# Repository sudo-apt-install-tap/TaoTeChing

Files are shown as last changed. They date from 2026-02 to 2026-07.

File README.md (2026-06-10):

# Tao Te Ching

Split keyboard. Ortholinear grid with column stagger. Built for comfort and long sessions.

---

## Overview
Tao Te Ching is a **split mechanical keyboard** that combines the predictability of ortholinear rows with the ergonomics of column stagger. Each half is compact, symmetric, and designed to keep hands in a neutral position.

### Why?
This will be my first split keyboard. Ive seen many people make splits. But nearly noone uses custom layout. So I made this layout.

### How?
You can write up a simple firmware or use the KMK script in my repo.

---

## Layout
- Split, mirrored halves  
- Ortholinear rows with column stagger  
- Compact layout with outer thumb/utility keys  
- Optimized for touch typing and minimal finger travel

See renders and PCB files for exact spacing and geometry.

---

## Index:
- [Build Guide](https://github.com/sudo-apt-install-tap/TaoTeChing/blob/main/Build%20guide.md)
- [Build Images](https://github.com/sudo-apt-install-tap/TaoTeChing/blob/main/README.md#build-images)
- [Journal](tao-te-ching-journal.md)
- [Images](Images)
- [PCB](PCB)
- [Fimware](firmware)
- [CAD](CAD)
  
---

## Hardware
- MX-compatible switches  
- Per-key diodes (matrix)  
- Controller footprint suitable for XIAO-class boards  
- Board-to-board connection pads for split communication

Plates can be 3D-printed (PLA works) or CNCed.

---

## Firmware
Designed to work with common keyboard firmware:
- QMK / KMK / ZMK (controller-dependent)
I will use KMK

---

## Renders
- KiCAD Render: <br>
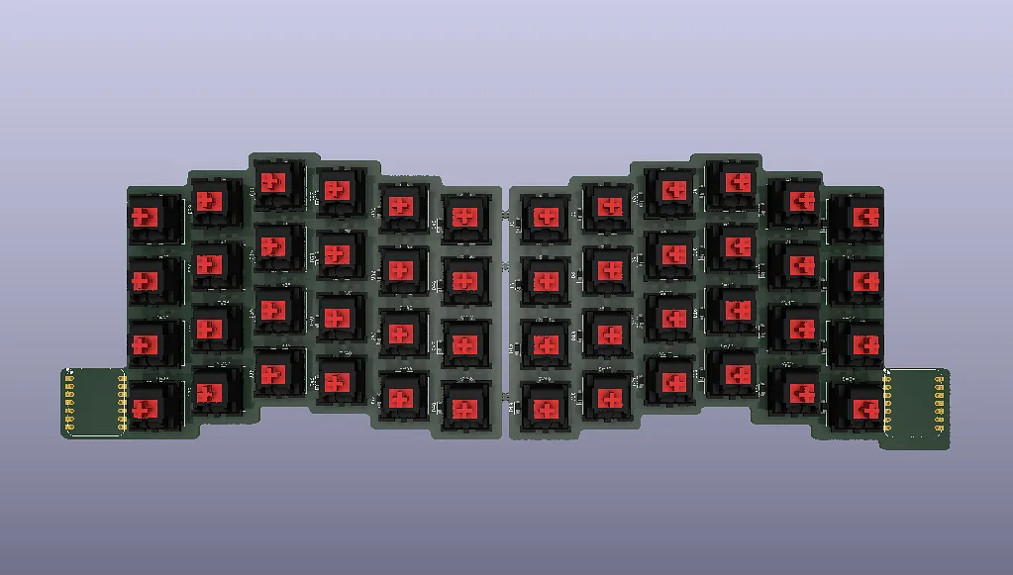
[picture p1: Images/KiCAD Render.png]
  
- CAD Exploded: <br>
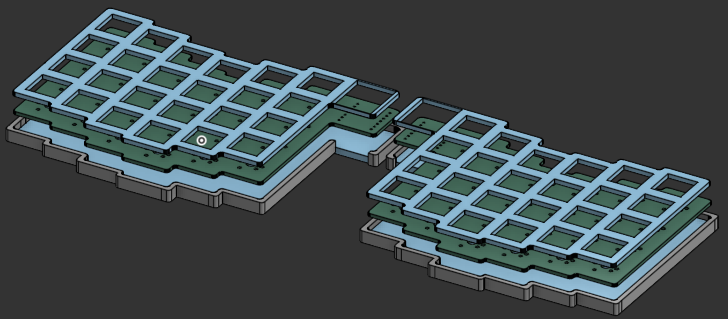
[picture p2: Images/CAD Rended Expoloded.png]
  
- CAD Assembled: <br>
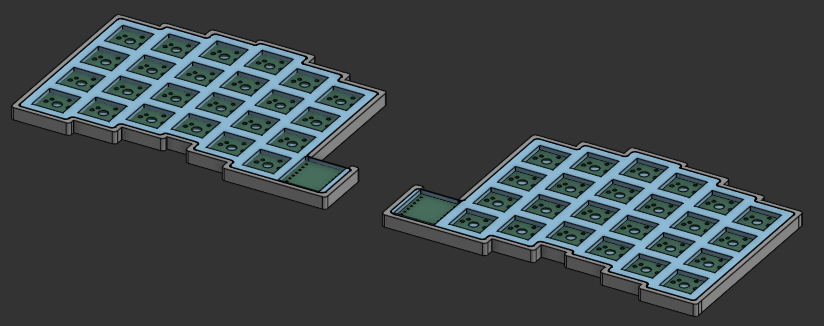
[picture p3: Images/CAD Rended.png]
  
- Left Case: <br>
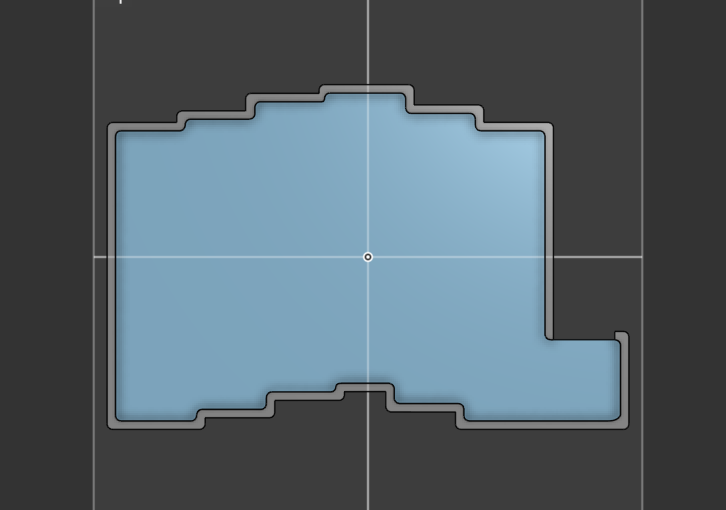
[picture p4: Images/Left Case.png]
  
- Right Case: <br>
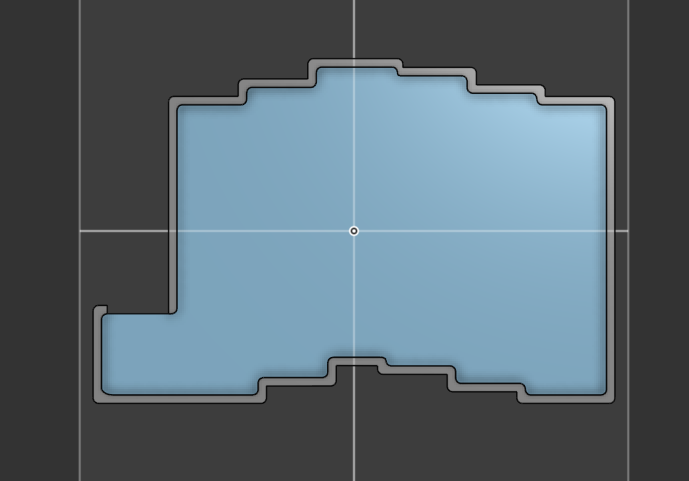
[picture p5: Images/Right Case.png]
  
- Left Plate: <br>
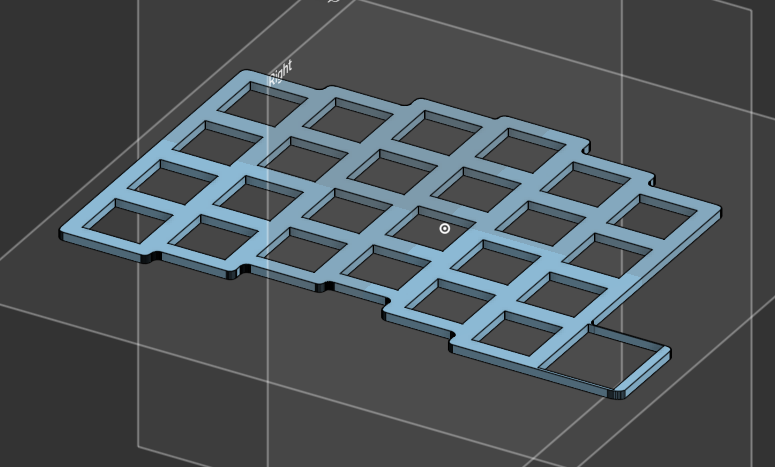
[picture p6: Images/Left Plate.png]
  
- Right Plate: <br>
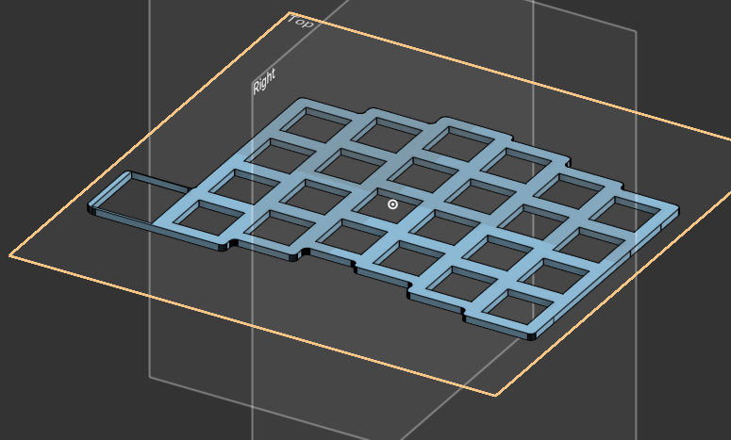
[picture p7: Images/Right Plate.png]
  
  
---

## KiCAD Images
- Layout: <br>
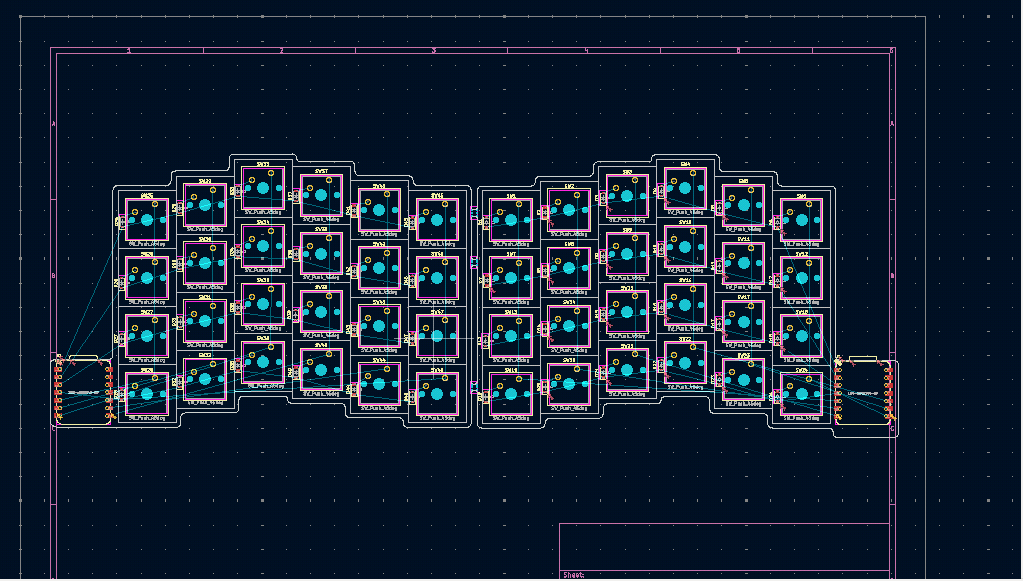
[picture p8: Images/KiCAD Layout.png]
  
- Left Sheet: <br>
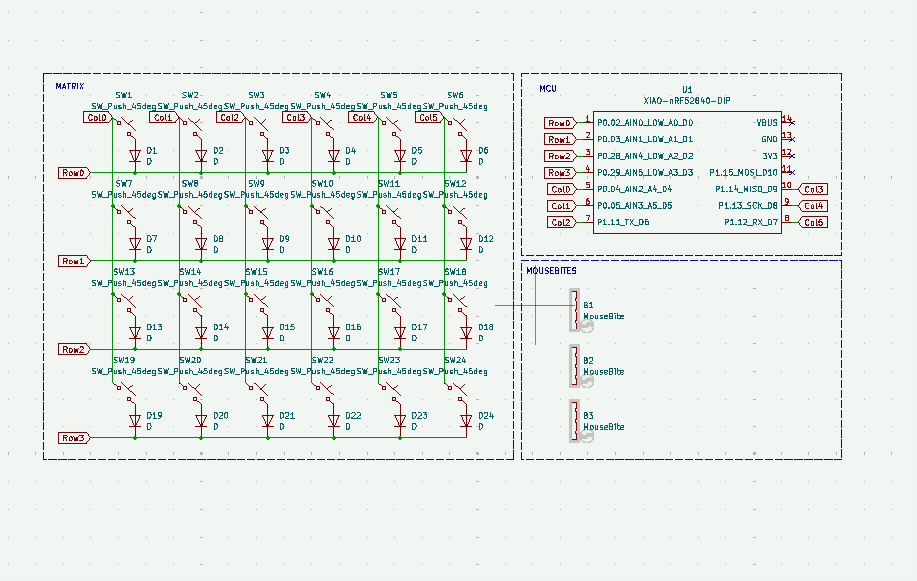
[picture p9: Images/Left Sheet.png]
  
- Right Sheet: <br>
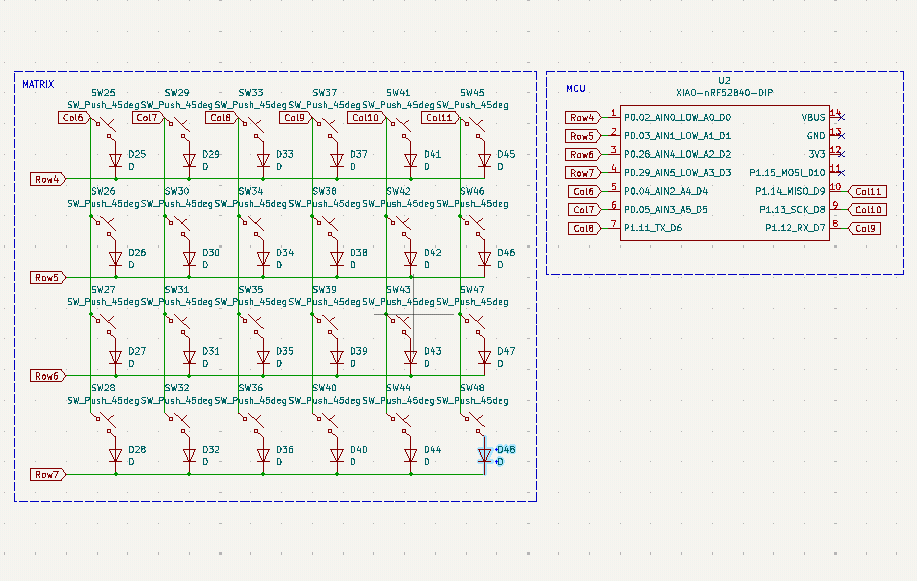
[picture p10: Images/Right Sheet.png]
  
- Wiring: <br>
  
  
---

## Project Status
- [x] Layout: finalized  
- [x] PCB: routed and rendered  
- [x] Prototypes: Done!
- [x] Revisions: Done!

### DONE!!

---

## Build Images And Videos
<div align="center">

 <br><br>
 <br><br>
 <br><br>
<br><br>
<br><br>
<br><br>
<br><br>

[TAO TE CHING DEMO](https://www.youtube.com/shorts/A5UJ3Mnc8bE)

</div>

---

# Bill of Materials (BOM)

| Item | Description | Cost (INR) |
|---|---|---:|
| Keycaps | Full keycap set | ₹1,400 |
| PCB | Custom PCB fabrication | ₹3,726 |
| Switches | Mechanical keyboard switches | ₹1,275 |
| Diodes | Per-key matrix diodes | ₹102 |
| MCU | Seeed Studio XIAO RP2040 | ₹1,236 |
| Case & Plate | 3D printed case and plate (shipping included) | ₹500 |
| **Total** |  | **₹8,239** |

> **Project Cost:** ₹8,239 (~$95 USD)

## CAD SOURCE FILES AVAILABLE!

[ONSHAPE](https://cad.onshape.com/documents/3a64b1ece82f2d5ea6875226/w/4aeac85fe30a56c6319ae754/e/e0c4af6436b0f9ae25f54182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)

---

## License
Open source. Build it, modify it, improve it.

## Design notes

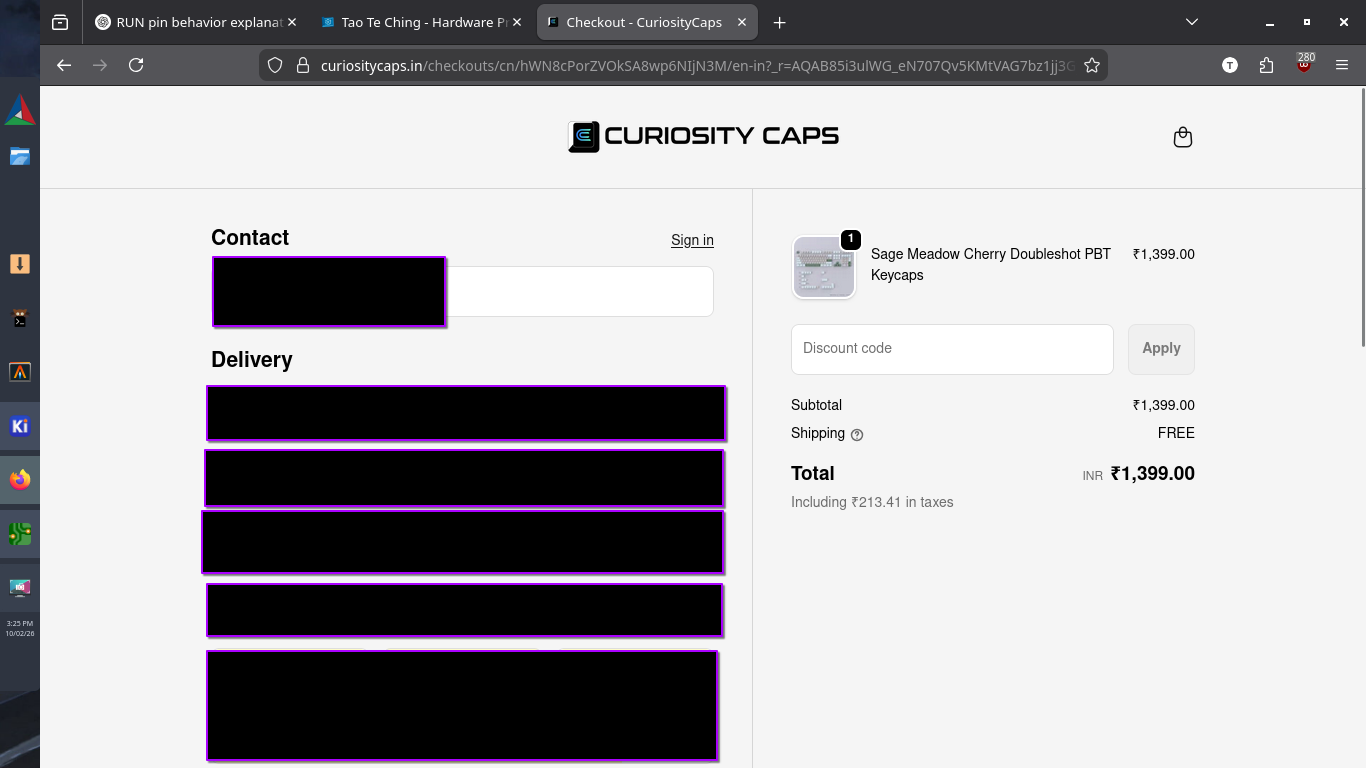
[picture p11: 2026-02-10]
Images/CART/Keycaps.png

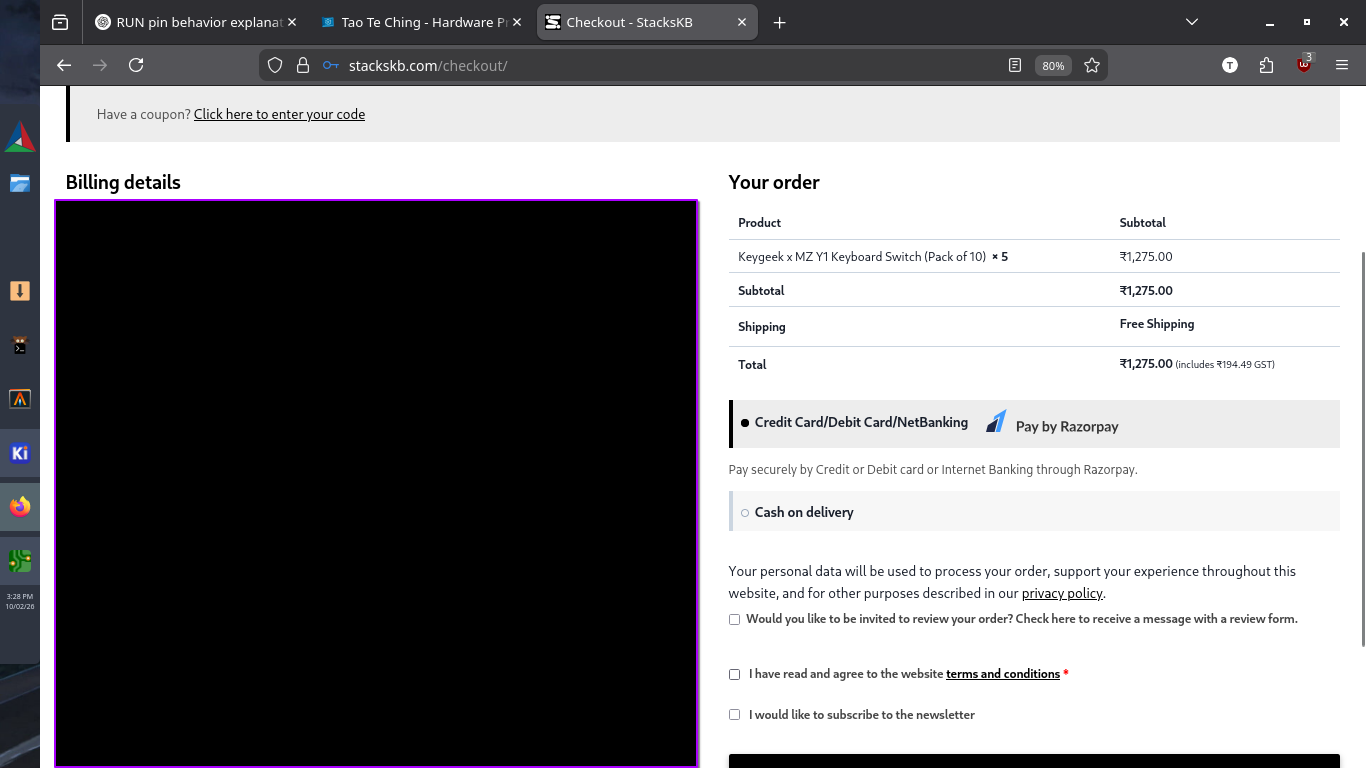
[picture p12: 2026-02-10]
Images/CART/StackKB Switches.png

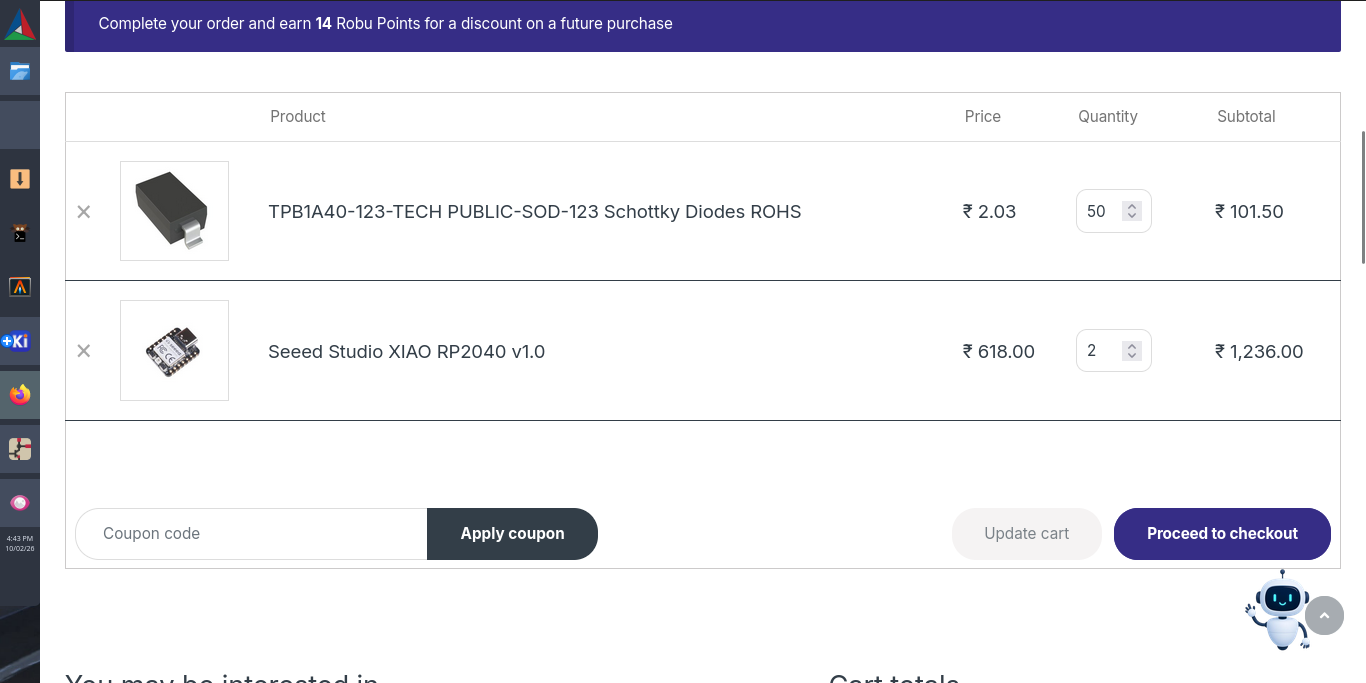
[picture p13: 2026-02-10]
Images/CART/Robu MCU + Diodes.png

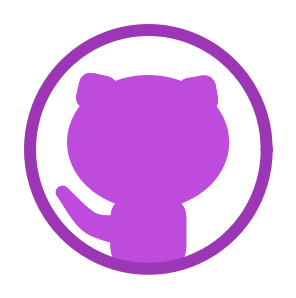
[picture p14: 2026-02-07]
Images/Git.png

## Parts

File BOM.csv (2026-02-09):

Id | Designator | Footprint | Quantity | Designation | Supplier and ref
1 | D22,D38,D41,D42,D44,D19,D25,D39,D40,D23,D16,D18,D35,D24,D17,D14,D48,D32,D27,D5,D13,D29,D28,D7,D6,D8,D1,D45,D21,D46,D43,D33,D15,D10,D34,D4,D30,D3,D37,D2,D36,D20,D26,D12,D11,D47,D31,D9 | D_SOD-123 | 48 | D
2 | SW17,SW30,SW38,SW12,SW33,SW23,SW46,SW28,SW45,SW13,SW24,SW44,SW35,SW2,SW42,SW20,SW22,SW43,SW11,SW4,SW47,SW36,SW9,SW41,SW26,SW39,SW48,SW18,SW6,SW7,SW15,SW1,SW5,SW27,SW8,SW31,SW21,SW40,SW16,SW37,SW14,SW29,SW10,SW32,SW3,SW34,SW25,SW19 | SW_Cherry_MX_1.00u_PCB | 48 | SW_Push_45deg
3 | U1,U2 | XIAO-nRF52840-DIP | 2 | XIAO-nRF52840-DIP

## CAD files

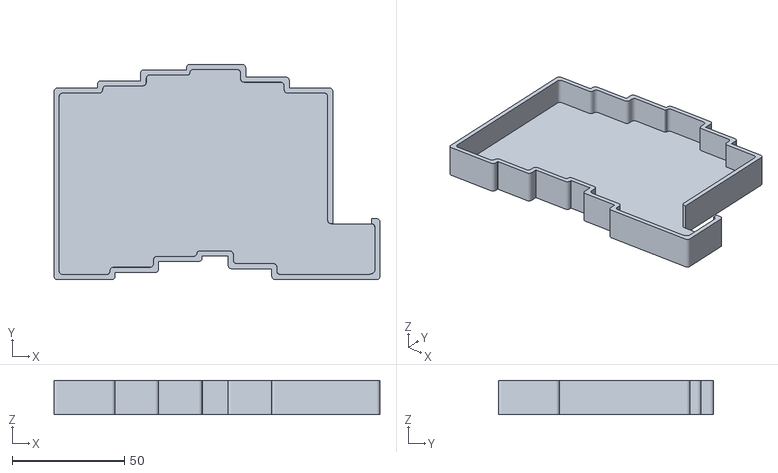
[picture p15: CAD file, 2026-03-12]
CAD/Case/Left Case.stl
145.5 x 96.1 x 15.3

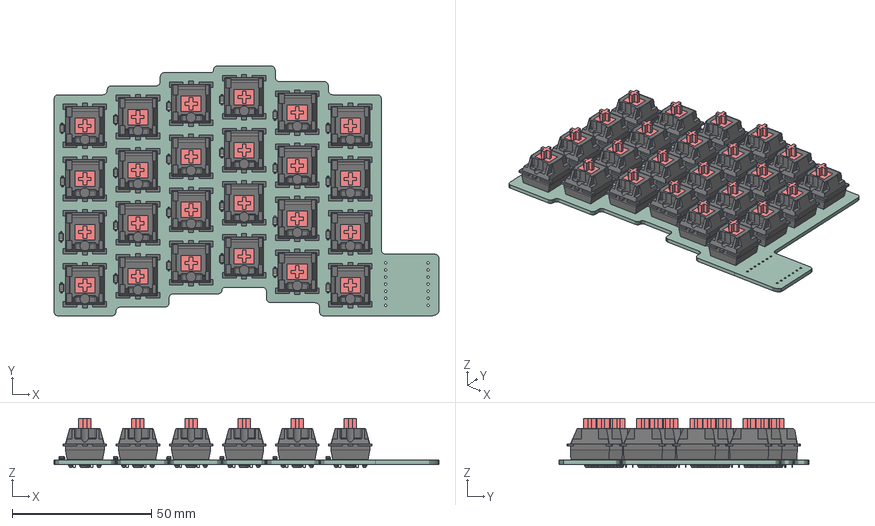
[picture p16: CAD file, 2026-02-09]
CAD/PCB CAD/Tao Te Ching LEFT.step
138.1 x 89.7 x 17.7 mm
D_SOD-123 x 24
Tao Te Ching LEFT_PCB

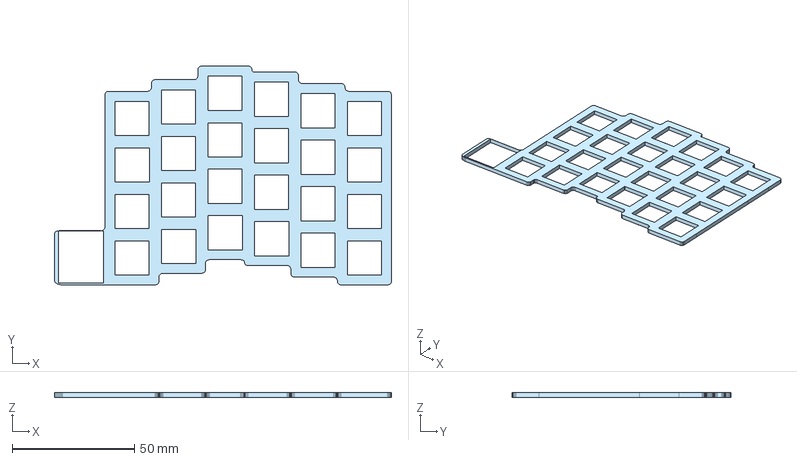
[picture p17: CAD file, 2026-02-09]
CAD/Plate/Plate Right.step
138.1 x 89.6 x 2.00 mm

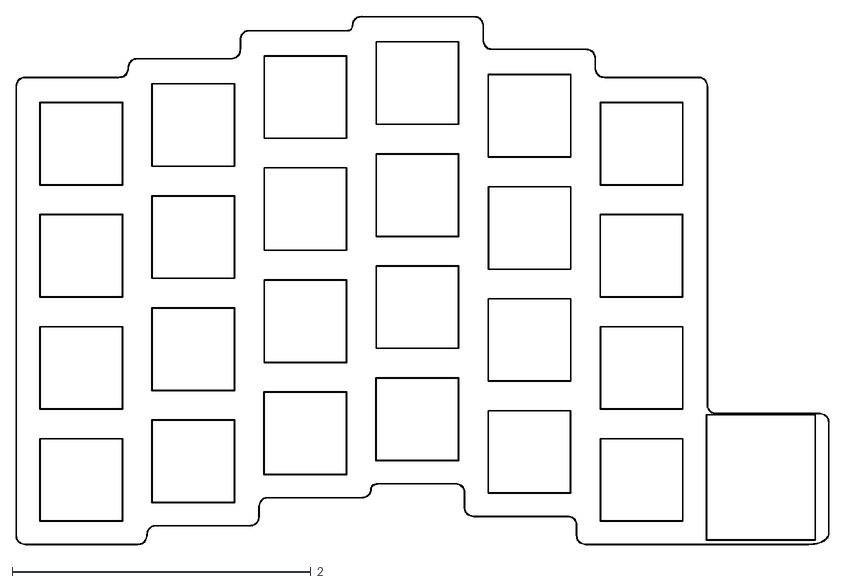
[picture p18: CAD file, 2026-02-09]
PCB/Segmented/Tao Te Ching LEFT For plate-Edge_Cuts.dxf
5.44 x 3.53

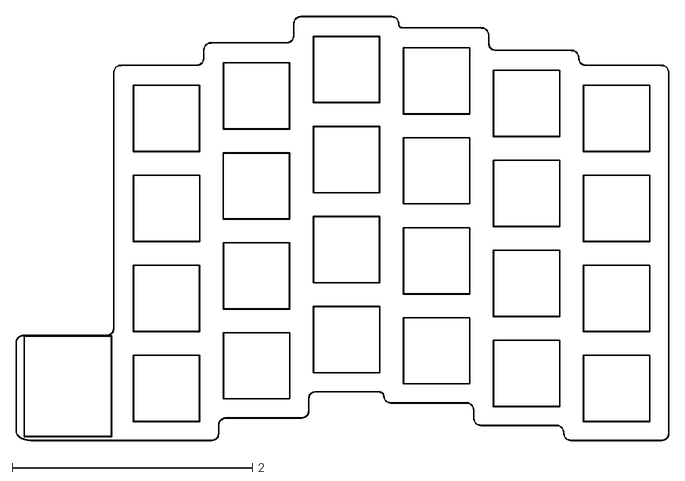
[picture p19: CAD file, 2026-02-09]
PCB/Segmented/Tao Te Ching RIGHT for plate-Edge_Cuts.dxf
5.44 x 3.53

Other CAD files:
CAD/Case/Right Case.stl
CAD/PCB CAD/Tao Te Ching RIGHT.step
CAD/Plate/Plate Left.step
PCB/Segmented/Tao Te Ching RIGHT.step

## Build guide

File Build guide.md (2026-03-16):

# BUILD GUIDE FOR TAO TE CHING <br>

## Intro:
<h4>Okay, now you have your PCB and components in hand and are ready to build it! I've tried to make this guide as comprehensive as possible, but you are free to improve it and submit a PR to this repo. </h4>
<br>

## Tools Required
- Soldering iron
- Solder
- Tweezers
- Flux (recommended)
- USB cable
- Multimeter (optional but helpful)

<br>

## Recommended Build Order
1. Solder diodes
2. Solder hotswap sockets
3. Solder MCU
4. Install switches
5. Flash firmware
6. Test the matrix

<br>

## Diodes
<h4>
N.T: Match the stripe on the diode with the line on the PCB silkscreen. The stripe indicates the cathode. If the diode is reversed the keyboard matrix will not work. <br><br>

Firstly tin one of the pads of the diodes, then using tweezers hold the diodes down and then melt the solder and hold it. In the end it should look something like this: </h4>
<br>
<div align="center">

</div>

## HotSwap Sockets
<h4> N.T: I have used TTC Pokayoke Hotswap Sockets V2 which are compatible with Kailh socket footprints and are reversable. If you have used Kailh or any other sockets which are NOT reversible please pay attention to the orientation as it can cause problems later down the line while snapping in the plate. <br><br>

I recommend not tinning the pads before putting the sockets in. So you just want to place the sockets in the hole and align it with the footprint. Now you want to add solder to the pads. Keep the solder molten and switch to your tweezers to now put pressure on the socket so it sits flush. Now after it has solidified, solder the other pad too. Now! It should look like this: </h4>
<div align="center">

</div>
<br>

## MCU
<h4> For the Tao Te Ching keyboard I used the <b>XIAO RP2350</b>. Make sure the MCU is oriented correctly before soldering it to the PCB. Incorrect orientation may prevent the keyboard from functioning or could damage the board. <br><br>

First place the MCU onto the footprint and ensure that all pins line up properly with the pads on the PCB. Once aligned, you may want to temporarily secure the board with a small piece of tape or hold it in place while soldering. <br><br>

Begin by soldering <b>one corner pin</b>. After this, check that the MCU sits flat against the PCB and that all pins are aligned correctly. If necessary, reheat the solder joint and adjust the position of the MCU. <br><br>

Once you are satisfied with the alignment, proceed to solder the remaining pins. Take your time and make sure each pin is properly connected to its pad. <br><br>

After soldering, visually inspect the pins to ensure there are <b>no solder bridges</b> between them.
</h4>
<div align="center">

</div>
<br>

## Switches:
<h4>
  For the switches you can just press the switches into the plate and then align the plate with the PCB and HotSwap sockets and just push them in column by column. Theres not much to do here!
</h4> <br>

## Firmware: 
While pressing down the boot button on your MCU plug it in, wait till a drive pops up. Get the circuitpython uf2 from [HERE](https://circuitpython.org/board/seeeduino_xiao_rp2350/). <br> <br>
Add /kmk from the kmk library from [HERE](https://github.com/KMKfw/kmk_firmware) to the drive that appears. <br> <br> Now get the code from [/firmware](firmware) and add it to the respective MCUs.

## AND YOU ARE DONE!!!

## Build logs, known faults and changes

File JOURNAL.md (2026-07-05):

---
title: "Tao Te Ching"
author: "Tap"
description: "A open-source split keyboard made for ergonomics!! Made to feel minimalist. This is a ortholinear keyboard."
created_at: "2026-02-05"
---

# February 5: Made The Schematic + Keyboard Layout

Made the schematic and finalized the split keeb layout. It’s ortholinear-staggered with wireless support but I’ll be using it wired only. Followed a guide loosely. Parts are placed, wiring left for tomorrow. It’s finally starting to feel like something id use!

The xiao nrf52 is great as it has battery charging in built and also has BLE for longer run time and is compact and has enough GPIO. Also I went with standard mx keys because parts are easily availabe.

> NOTE: later I moved to XIAO rp2040 which is equally as good just without the RF and BLE capabilities.

- SCHEMATIC

Left Sheet

Right Sheet

- PCB Layout

KiCAD Layout

- KiCAD Render

KiCAD Render

**Total time spent: 4hour 30minutes**

# February 6: Routed The PCB

Finished routing the PCB today and it honestly went smoother than I expected. Just wired everything up cleanly and it all came together without much headache. Also first project where I didn’t use a ground pour since there weren’t any external power-hungry parts involved, which felt kinda unusual but neat in a way. I do really like that I did not use neopixles as that woulve made me cry while routing.

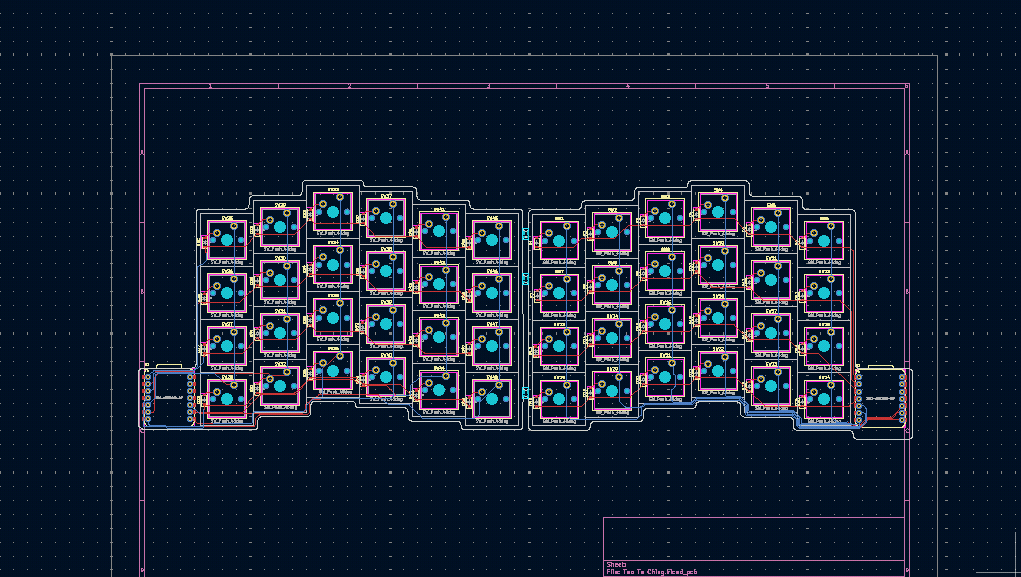
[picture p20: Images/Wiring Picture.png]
Wiring Picture


**Total time spent: 1hour 30minutes**

# February 9: Made The Case

I had to make the case twice because the first version turned out wrong. I realized both sides weren’t properly mirrored.

CAD Rended Expoloded

That meant going back and retracing every line in the DXF used for both the inner and outer parts of the case. A bit tedious, but honestly kind of satisfying in a “fix it properly or suffer later” way.

But in the end it all came together, and I think it looks pretty rad.

CAD Rended

Left Case

Left Plate

Right Case

Right Plate

**Total time spent: 5hour**

# February 9: Added art to the silkscreen

Added a bit of personality to the PCB today by putting artwork on the silkscreen. This part was honestly really fun. Feels like the “final touch” stage where the board stops being just a project and starts feeling like a finished thing that I can use.

Used KiCad’s image conversion tool to get it done, which made the process pretty smooth.

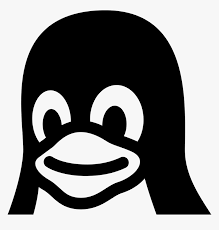
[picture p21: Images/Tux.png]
Tux


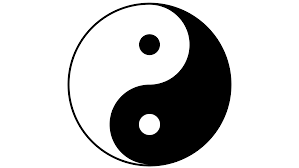
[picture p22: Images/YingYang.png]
YingYang


**Total time spent: 30minutes**

# February 10: Wrote the readme and organized all cart images!

Finished up the project today by writing the README and dusting up all the images for the GitHub page. This was basically the final polish step.

Honestly, I enjoyed every part of this build, schematic to case to silkscreen. It taught me a lot more than I expected going in.

Here’s the final GitHub page:




**Total time spent: 1hour**

# February 23: Added HotSwap Sockets

Saw that most split keyboards use hotswap sockets, so I decided to add them too. Should make the board a lot more flexible and easier to experiment with switches later.

It took some time (and patience), but it was worth it. More soldering, but in a good way.

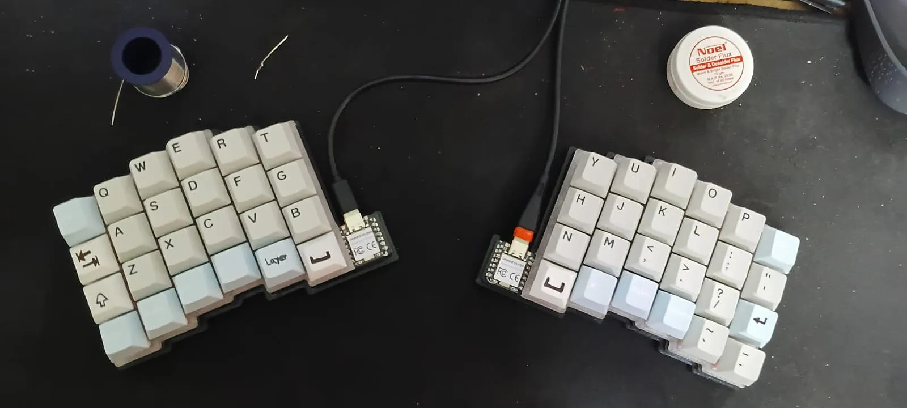
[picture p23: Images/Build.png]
Build


**Total time spent: 3hour**

# February 26: Ordered All The Parts!

Ran into a small hiccup today — the MCU I originally planned to use, the [XIAO RP2040](https://robu.in/product/seeed-studio-xiao-rp2040-v1-0/), was out of stock 😕. So I switched to the Seeed Studio [XIAO RP2350](https://robu.in/product/seeedstudio-xiao-rp2350-raspberry-pi-rp2350/) instead. Slight change, thanks to the XIAO form factor.

Everything else went pretty smoothly though. I’ve also ordered the prints, but my printer is out of light grey PLA, so I’ll have to wait a bit before those come in.

Other than that… it’s basically all set. Just waiting on parts now.

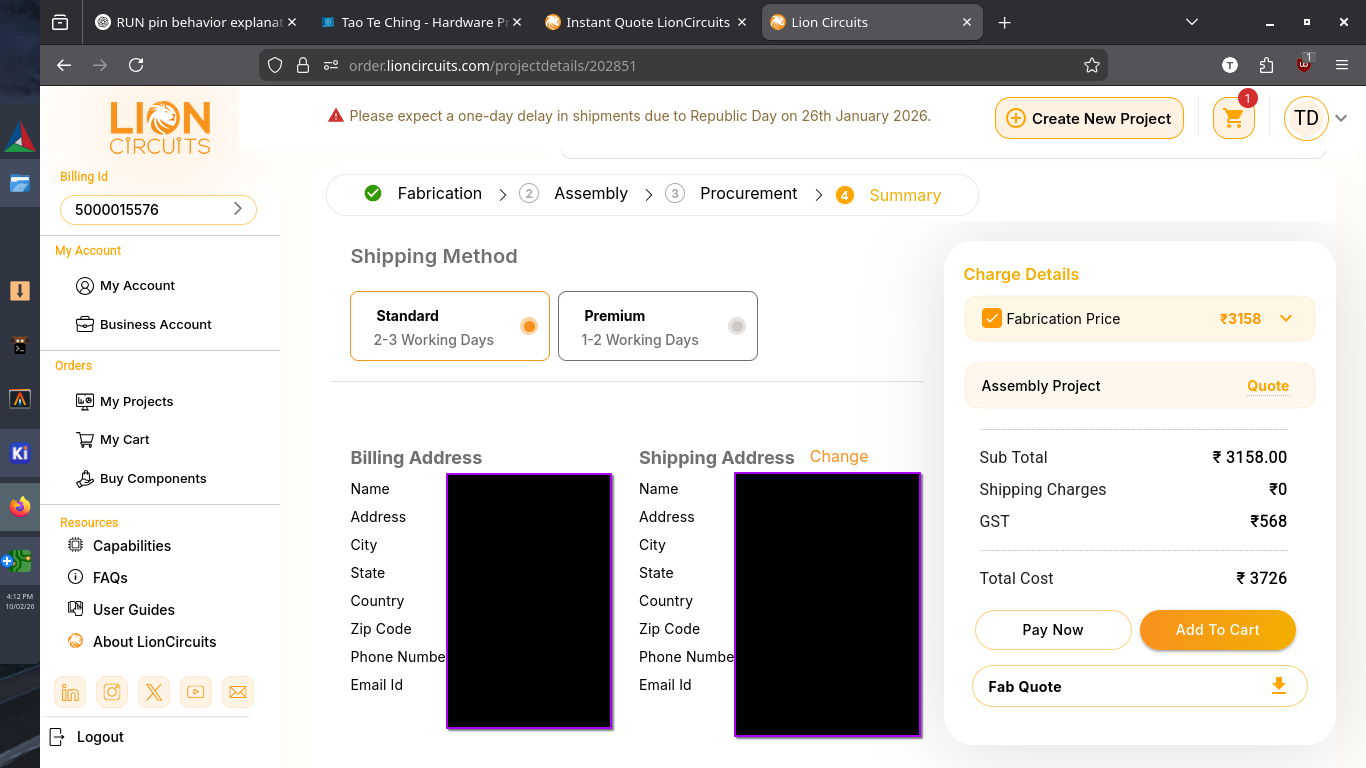
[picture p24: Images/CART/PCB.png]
PCB


**Total time spent: 2hour**

# March 12: Fixed Case Height!

The case walls were too shallow, so I couldn’t fit the plate inside properly. Had to go back and redesign both sides to fix the height issue.

A bit annoying, but honestly expected at least one hassle like this. I think I will print this new one.

Left Case

**Total time spent: 1hour**

# March 14: Got all the items!!

Finally received all the PCBs, which means I’ve got everything needed to start assembly now. Had to pay around $5 in customs -kinda annoying, but not too bad in the grand scheme of things (I once had to give 25usd worth of customs for a devboard that I designed and that did not work.

Everything else looks *near* perfect though.

The only downside is that due to print restrictions I can only get one case print, so the newer revised case design won’t really be usable. Bit of a bummer.

PCB

**Total time spent: 1hour 30minutes**

# March 15: Soldered the PCB.

So yeah, I finally got around to soldering the PCB. It took a while because of the number of SMD diodes on each half, and they really slow you down when you’re trying to stay precise. I also ran out of solder midway, so I had to step out and grab more from a local store before continuing.

The diodes were the most time-consuming part each one had to be placed with tweezers, tacked on one side first, then carefully reflowed on the other to keep everything aligned and clean. Slow process, but it kept things neat.

After that I moved on to the hotswap sockets. I aligned each one on its footprint, tinned a single corner pin to lock it in place, and then went back to solder the remaining pins once everything was sitting properly. Much faster than the diodes, but still required attention to avoid any tilt or misalignment.

Except for the solder shortage pause, everything else felt pretty smooth and intuitive once I got into the rhythm.

Here are some pics:







**Total time spent: 5hour 30minutes**

# March 16: Redid the code(had no importance)!! and possibly becoming bald? Soldering the XIAO!

So I had to redo the code today after realizing the previous version just wasn’t working properly. On top of that, I had to troubleshoot the right side since it wasn’t responding at all.

Turns out the issue was way simpler (and more embarrassing) than expected I had literally just pushed the MCU into its place thinking it would work fine like that… spoiler: it didn’t. Took me around 4 hours of confusion and “why is this not working” before I figured that out. :>

This wasnt really a firmware issue but a skill issue!

> ripped my old mouse pad while doing so

Once that was done, I rewrote and cleaned up the KMK script and started to work on the features and stuff. VERY Painful lesson, but a useful one.

Also chatgpt just provided me with the template for the project and I just had to change the pins and stuff!



<br><br>
<br><br>
<br><br>
<br><br>

**Total time spent: 4hour**

# March 16: Revised the readme and added build guide

Cleaned up the README today and added a proper index so you can actually click through sections and files without scrolling forever. Makes the whole repo feel way more structured and usable.

Also added a full build guide mostly for the looks and future-me, because realistically not many people are going to build this exact thing… but it felt right to include anyway.

Now the project feels less like 'a bunch of files' and more like an actual documented build. Which is good!




**Total time spent: 2hour**

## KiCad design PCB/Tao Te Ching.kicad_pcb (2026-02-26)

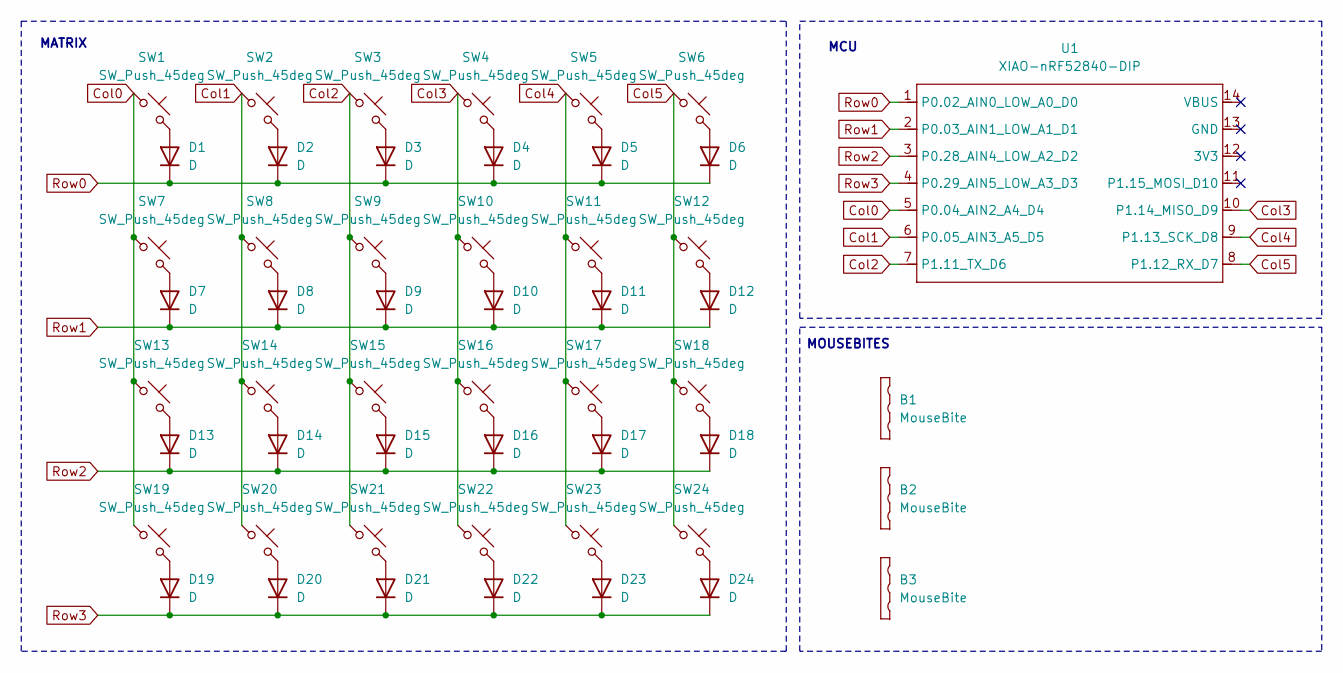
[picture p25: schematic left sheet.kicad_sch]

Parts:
B1, B2, B3: MouseBite; MouseBite-Slot_2.0x2.0mm_outset_D0.5mm_P0.85mm_3h
D1, D2, D3, D4, D5, D6, D7, D8, D9, D10, D11, D12, D13, D14, D15, D16, D17, D18, D19, D20, D21, D22, D23, D24: D; D_SOD-123
SW1, SW2, SW3, SW4, SW5, SW6, SW7, SW8, SW9, SW10, SW11, SW12, SW13, SW14, SW15, SW16, SW17, SW18, SW19, SW20, SW21, SW22, SW23, SW24: SW_Push_45deg; SW_Hotswap_Kailh_MX
U1: XIAO-nRF52840-DIP

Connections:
Col0: SW1.1, SW7.1, SW13.1, SW19.1, U1.5 (P0.04_AIN2_A4_D4)
Col1: SW2.1, SW8.1, SW14.1, SW20.1, U1.6 (P0.05_AIN3_A5_D5)
Col2: SW3.1, SW9.1, SW15.1, SW21.1, U1.7 (P1.11_TX_D6)
Col3: SW4.1, SW10.1, SW16.1, SW22.1, U1.10 (P1.14_MISO_D9)
Col4: SW5.1, SW11.1, SW17.1, SW23.1, U1.9 (P1.13_SCK_D8)
Col5: SW6.1, SW12.1, SW18.1, SW24.1, U1.8 (P1.12_RX_D7)
unnamed: D1.2 (A), SW1.2
unnamed: D2.2 (A), SW2.2
unnamed: D3.2 (A), SW3.2
unnamed: D4.2 (A), SW4.2
unnamed: D5.2 (A), SW5.2
unnamed: D6.2 (A), SW6.2
unnamed: D7.2 (A), SW7.2
unnamed: D8.2 (A), SW8.2
unnamed: D9.2 (A), SW9.2
unnamed: D10.2 (A), SW10.2
unnamed: D11.2 (A), SW11.2
unnamed: D12.2 (A), SW12.2
unnamed: D13.2 (A), SW13.2
unnamed: D14.2 (A), SW14.2
unnamed: D15.2 (A), SW15.2
unnamed: D16.2 (A), SW16.2
unnamed: D17.2 (A), SW17.2
unnamed: D18.2 (A), SW18.2
unnamed: D19.2 (A), SW19.2
unnamed: D20.2 (A), SW20.2
unnamed: D21.2 (A), SW21.2
unnamed: D22.2 (A), SW22.2
unnamed: D23.2 (A), SW23.2
unnamed: D24.2 (A), SW24.2
Row0: D1.1 (K), D2.1 (K), D3.1 (K), D4.1 (K), D5.1 (K), D6.1 (K), U1.1 (P0.02_AIN0_LOW_A0_D0)
Row1: D7.1 (K), D8.1 (K), D9.1 (K), D10.1 (K), D11.1 (K), D12.1 (K), U1.2 (P0.03_AIN1_LOW_A1_D1)
Row2: D13.1 (K), D14.1 (K), D15.1 (K), D16.1 (K), D17.1 (K), D18.1 (K), U1.3 (P0.28_AIN4_LOW_A2_D2)
Row3: D19.1 (K), D20.1 (K), D21.1 (K), D22.1 (K), D23.1 (K), D24.1 (K), U1.4 (P0.29_AIN5_LOW_A3_D3)

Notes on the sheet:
MOUSEBITES
MATRIX
MCU

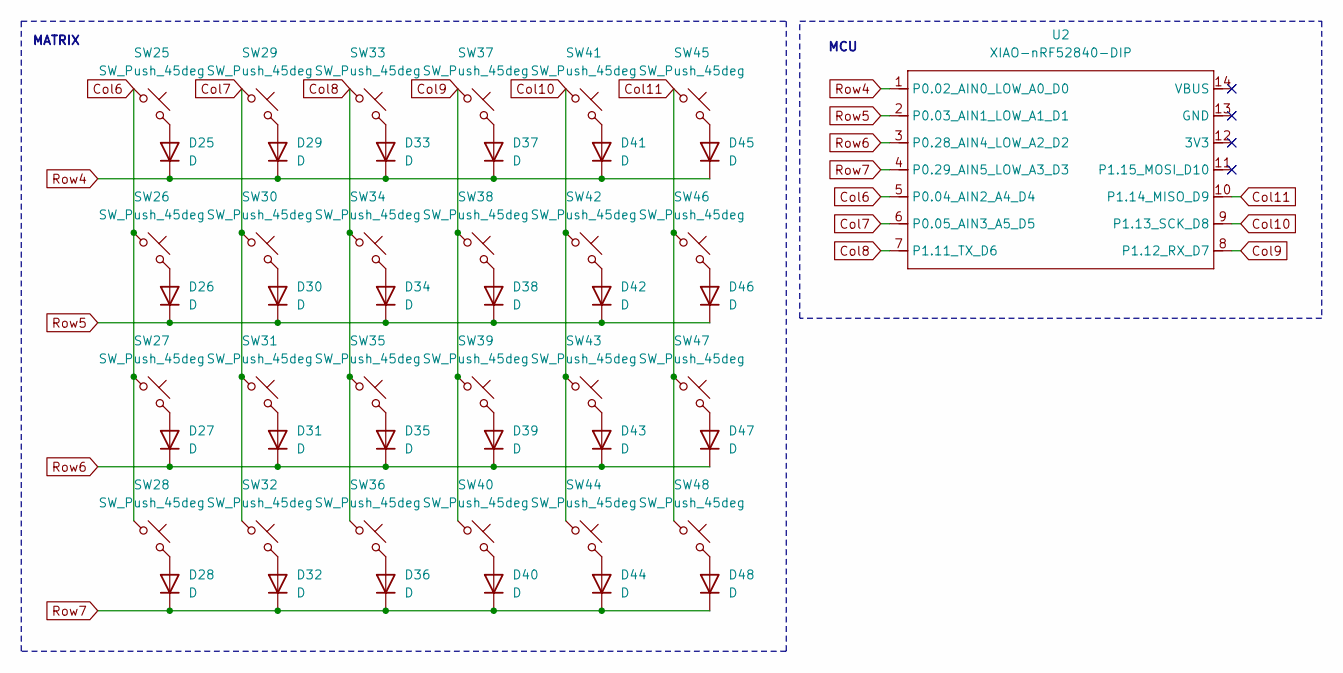
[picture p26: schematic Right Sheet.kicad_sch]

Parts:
D25, D26, D27, D28, D29, D30, D31, D32, D33, D34, D35, D36, D37, D38, D39, D40, D41, D42, D43, D44, D45, D46, D47, D48: D; D_SOD-123
SW25, SW26, SW27, SW28, SW29, SW30, SW31, SW32, SW33, SW34, SW35, SW36, SW37, SW38, SW39, SW40, SW41, SW42, SW43, SW44, SW45, SW46, SW47, SW48: SW_Push_45deg; SW_Hotswap_Kailh_MX
U2: XIAO-nRF52840-DIP

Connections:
Col6: SW25.1, SW26.1, SW27.1, SW28.1, U2.5 (P0.04_AIN2_A4_D4)
Col7: SW29.1, SW30.1, SW31.1, SW32.1, U2.6 (P0.05_AIN3_A5_D5)
Col8: SW33.1, SW34.1, SW35.1, SW36.1, U2.7 (P1.11_TX_D6)
Col9: SW37.1, SW38.1, SW39.1, SW40.1, U2.8 (P1.12_RX_D7)
Col10: SW41.1, SW42.1, SW43.1, SW44.1, U2.9 (P1.13_SCK_D8)
Col11: SW45.1, SW46.1, SW47.1, SW48.1, U2.10 (P1.14_MISO_D9)
unnamed: D25.2 (A), SW25.2
unnamed: D26.2 (A), SW26.2
unnamed: D27.2 (A), SW27.2
unnamed: D28.2 (A), SW28.2
unnamed: D29.2 (A), SW29.2
unnamed: D30.2 (A), SW30.2
unnamed: D31.2 (A), SW31.2
unnamed: D32.2 (A), SW32.2
unnamed: D33.2 (A), SW33.2
unnamed: D34.2 (A), SW34.2
unnamed: D35.2 (A), SW35.2
unnamed: D36.2 (A), SW36.2
unnamed: D37.2 (A), SW37.2
unnamed: D38.2 (A), SW38.2
unnamed: D39.2 (A), SW39.2
unnamed: D40.2 (A), SW40.2
unnamed: D41.2 (A), SW41.2
unnamed: D42.2 (A), SW42.2
unnamed: D43.2 (A), SW43.2
unnamed: D44.2 (A), SW44.2
unnamed: D45.2 (A), SW45.2
unnamed: D46.2 (A), SW46.2
unnamed: D47.2 (A), SW47.2
unnamed: D48.2 (A), SW48.2
Row4: D25.1 (K), D29.1 (K), D33.1 (K), D37.1 (K), D41.1 (K), D45.1 (K), U2.1 (P0.02_AIN0_LOW_A0_D0)
Row5: D26.1 (K), D30.1 (K), D34.1 (K), D38.1 (K), D42.1 (K), D46.1 (K), U2.2 (P0.03_AIN1_LOW_A1_D1)
Row6: D27.1 (K), D31.1 (K), D35.1 (K), D39.1 (K), D43.1 (K), D47.1 (K), U2.3 (P0.28_AIN4_LOW_A2_D2)
Row7: D28.1 (K), D32.1 (K), D36.1 (K), D40.1 (K), D44.1 (K), D48.1 (K), U2.4 (P0.29_AIN5_LOW_A3_D3)

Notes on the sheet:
MATRIX
MCU

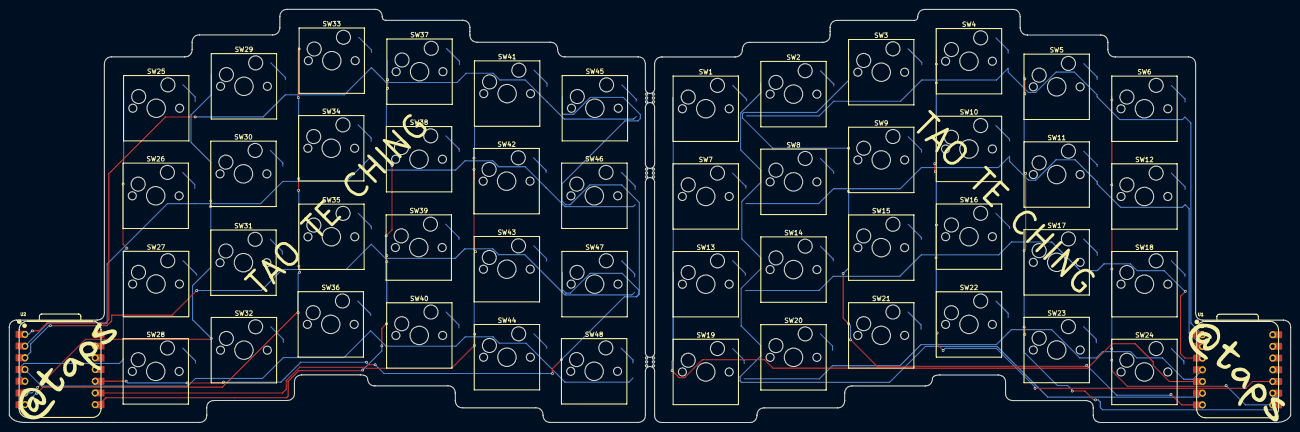
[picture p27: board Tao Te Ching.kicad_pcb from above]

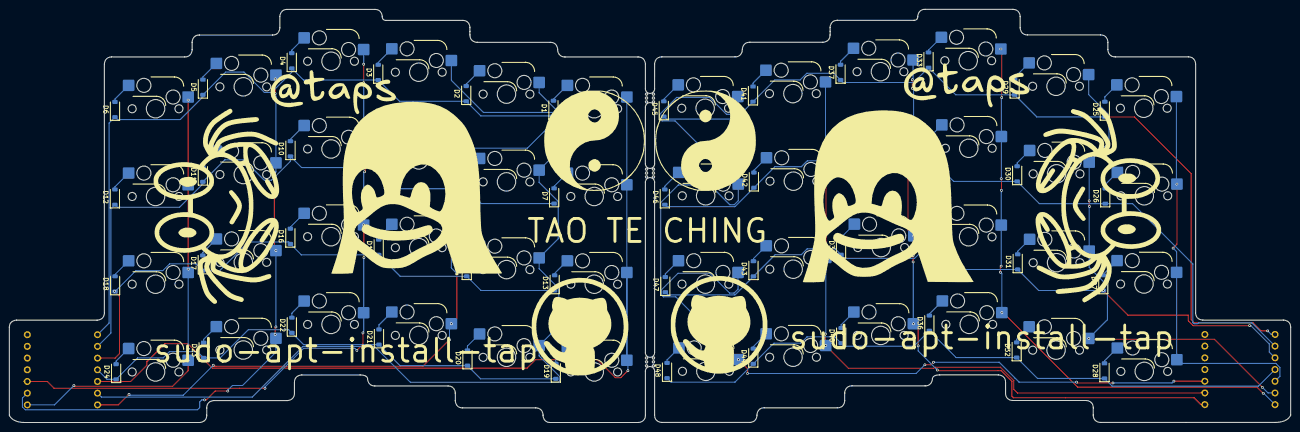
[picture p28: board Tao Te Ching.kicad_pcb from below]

Board: 2 copper layers, 278.2 x 89.7 mm, 101 parts (48 on the bottom side), 68 nets.

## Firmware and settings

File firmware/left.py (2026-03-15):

import board

from kmk.kmk_keyboard import KMKKeyboard
from kmk.keys import KC
from kmk.modules.layers import Layers
from kmk.scanners import DiodeOrientation

keyboard = KMKKeyboard()

layers = Layers()
keyboard.modules.append(layers)

keyboard.row_pins = (board.D0, board.D1, board.D2, board.D3)
keyboard.col_pins = (board.D4, board.D5, board.D6, board.D9, board.D8, board.D7)

keyboard.diode_orientation = DiodeOrientation.COL2ROW
keyboard.keymap = [

# Layer 0
[
KC.ESC, KC.Q, KC.W, KC.E, KC.R, KC.T,
KC.TAB, KC.A, KC.S, KC.D, KC.F, KC.G,
KC.LSHIFT, KC.Z, KC.X, KC.C, KC.V, KC.B,
KC.LCTRL, KC.LGUI, KC.LALT, KC.MO(1), KC.MO(2), KC.SPACE
],

# Layer 1 (Fn)
[
KC.GRAVE, KC.N1, KC.N2, KC.N3, KC.N4, KC.N5,
KC.TRNS, KC.LEFT, KC.DOWN, KC.UP, KC.RIGHT, KC.TRNS,
KC.TRNS, KC.TRNS, KC.TRNS, KC.TRNS, KC.TRNS, KC.TRNS,
KC.TRNS, KC.HOME, KC.END, KC.TRNS, KC.TRNS, KC.ENTER
],

# Layer 2
[
KC.F1, KC.F2, KC.F3, KC.F4, KC.F5, KC.F6,
KC.TRNS, KC.TRNS, KC.TRNS, KC.TRNS, KC.TRNS, KC.TRNS,
KC.TRNS, KC.TRNS, KC.TRNS, KC.TRNS, KC.TRNS, KC.TRNS,
KC.TRNS, KC.TRNS, KC.TRNS, KC.TRNS, KC.TRNS, KC.TRNS
]

]


if __name__ == "__main__":
    keyboard.go()

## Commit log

2026-02-07 Updated PCB and Added /Images
    [Left-Case.dxf, Right-Case.dxf, Tao Te Ching L.kicad_pcb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]
2026-02-09 Reworked Case and images
    [Left Case.step, Left-Case.dxf, Plate Left.step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]
2026-02-09 Enhance README with motivation and additional images
    Added sections on project motivation, firmware usage, and KiCAD images.
2026-02-09 Added silkscreen art
    [BOM.csv, Tao Te Ching.kicad_pcb]
2026-02-10 Added firmware
    [Tao Te Ching-B_Cu.gbr, Tao Te Ching-B_Mask.gbr, Tao Te Ching-B_Paste.gbr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]
2026-02-10 Add Bill Of Materials to README
    Added Bill Of Materials section with cost breakdown.
2026-02-24 Add CAD source files section to README
    Added a section for CAD source files with a link to Onshape.
2026-02-26 Added hotswap sockets
    [Right Sheet.kicad_sch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]
2026-03-12 Added Case STLs
    [Left Case.step, Left Case.stl, Right Case.step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]
2026-03-15 Updated Firmware
    [Right Sheet.kicad_sch, left sheet.kicad_sch]
2026-03-16 Create build guide for Tao Te Ching keyboard
    Added a comprehensive build guide for the Tao Te Ching keyboard, including required tools, recommended build order, and detailed instructions for soldering components.
2026-06-10 Revise JOURNAL.md with project updates and details
    Updated JOURNAL.md with detailed entries on the keyboard project, including schematic, PCB routing, case design, artwork addition, and assembly progress. Enhanced clarity and structure throughout the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
